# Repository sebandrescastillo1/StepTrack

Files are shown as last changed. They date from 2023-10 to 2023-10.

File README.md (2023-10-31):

# StepTrack - Contador de pasos en escalera
Repositorio contador de pasos 
## Contenido
- Librerias_eagle: Contiene librería de componentes de EAGLE utilizados para el contador de pasos.
- Documentos: Contiene los informes entregables de ELO301
- Datasheets: Contiene los datasheets de los componentes y otros documentos de interés.
- Entregable_PCB: Archivos entregables para PCB - COM & XLSX
- StepTruck_Esquematico.csv: BOM de EAGLE
- StepTruck_Esquematico.pdf: Esquemático EAGLE en formato pdf
- StepTruck_Esquematico.sch: ESquemático EAGLE en formato sch
- StepTruck_Esquematico.brd: Diseño PCB EAGLE en formato brd

## Autores
Grupo 2 - ELO301 S2 2023
- Paula Cartagena
- Sebastian Castillo
- Sebastian Madariaga
- Juan Piñeiro

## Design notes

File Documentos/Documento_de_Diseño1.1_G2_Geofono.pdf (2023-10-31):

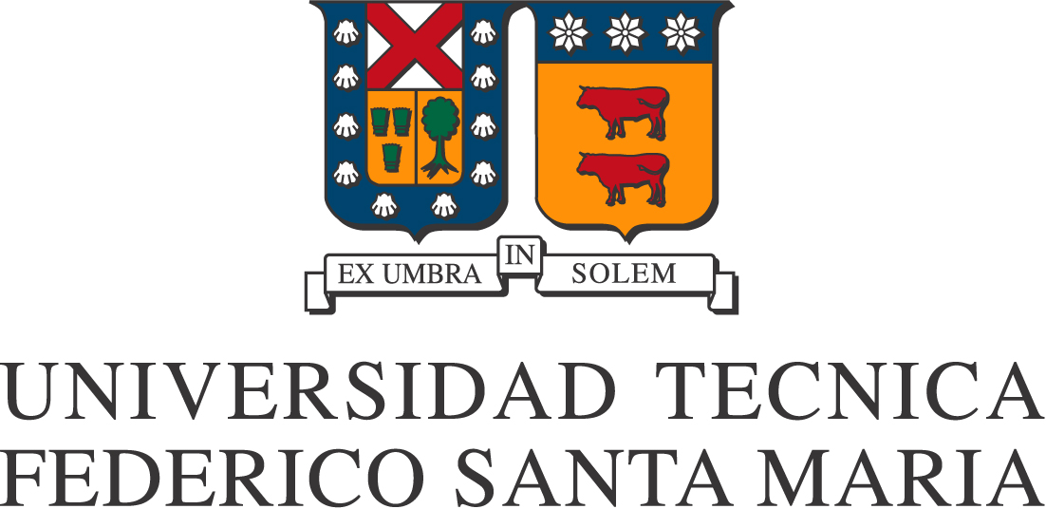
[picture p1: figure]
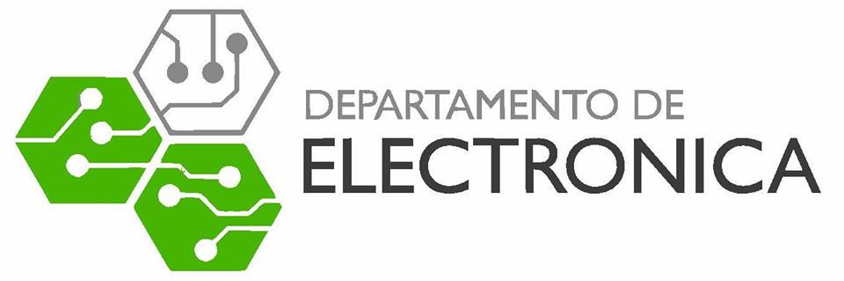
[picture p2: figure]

# Documento de diseño

# “Contador de pasos en escaleras”

Fecha | Revisión | Autor | Comentario
07/10/2023 | 1.0 | Paula Cartagena Sebastián Castillo Sebastián Madariaga Juan Piñeiro | Creación y desarrollo de documento
30/10/2023 | 1.1 | Paula Cartagena Sebastián Castillo Sebastián Madariaga Juan Piñeiro | Cambios de componentes a utilizar Cambio diagrama de bloques Cambio presupuesto y comentarios

Índice

1. Introducción. | 2
2. Funcionalidades Identificadas. | 3
2.1. Principales funcionalidades que debe cumplir el sistema | | 3
3. Elementos Identificados. | 3
3.1. | | | 3
4. Diseño de hardware propuesto. | 4
4.1. Diagrama de bloques | | 4
4.2. | | | 4
5. Diseño de firmware propuesto. | 5
5.1. Detalle de drivers | | 5
5.2. Diagrama de flujo | | 6
5.3. Detalle por módulo | | 6
6. Pruebas | 7
6.1. Prueba sobre elementos | | 7
| 6.1.1. Prueba 1: Prueba de geófono | | 7
| 6.1.2. Prueba 1: Prueba de geófono | | 8
6.2. Prueba sobre funcionalidades | | 8
| 6.2.1. Prueba 1 : Mensaje de Inicio | | 8
| 6.2.2. Prueba 2 : Prueba ADC | | 8
7. Cronograma | 9
8. Costos | 9

Índice de figuras

1. | Diagrama de Bloques | | 4
2. | Diagrama de flujo funcionamiento | | 6
Registro de especificaciones - Contador de pasos en escalera | 1

1 Introducción.

El sistema tiene la capacidad de contar la cantidad de pasos que se producen en una escalera mediante la detección de vibraciones capturadas por un geófono. Este dispositivo pasivo genera corriente eléctrica cuando capta vibraciones en su entorno, que en este caso es una escalera. Estas señales se digitalizan mediante un Convertidor Analógico a Digital (ADC) y luego se les aplica la Transformada Rápida de Fourier (FFT) para su filtrado y comparación con el estándar definido como "paso humano". Esto se logra mediante el análisis de los armónicos de frecuencia presentes en la señal. Si la señal cumple con los requisitos establecidos por el dispositivo, se lleva un registro de la cantidad de pasos ocurridos, junto con una marca de tiempo que indica el período de uso del equipo, es decir, desde el momento en que se conecta. Esta información, que incluye el número de pasos y la marca de tiempo, se envía en tiempo real en formato .csv al computador al que esté conectado a través de USB. Para reiniciar el conteo de pasos y la marca de tiempo, el dispositivo cuenta con un botón de reset.

Consideraciones:
El dispositivo se alimenta exclusivamente a través de un puerto USB de un computador, ya sea de USB-A o USB-C. Cuenta con un LED indicador de conexión que señala si está recibiendo energía, pero no garantiza una comunicación adecuada con el computador. Es responsabilidad del usuario verificar que la configuración de la comunicación esté correctamente ajustada de acuerdo al puerto COM de su portátil. Si se conecta a la red eléctrica mediante una caja de alimentación, el dispositivo pierde su funcionalidad principal.

Además, el dispositivo cuenta con un segundo LED que se enciende al recibir una señal de vibración proveniente del geófono. Este LED no indica la detección de un paso, sino simplemente la presencia de vibración, independientemente de su origen.

Es importante destacar que el dispositivo no almacena ningún tipo de dato. Sin embargo, cuenta con un pequeño búfer para almacenar el contador de pasos en caso de que se detecte una señal antes de que se pueda enviar la información al computador. La detección y el conteo de pasos son la prioridad, pero en caso de que este búfer se llene, se enviará toda la información a través de USB, sin importar si se pierde información, para evitar interrupciones. El dispositivo asume que la conexión con el computador siempre es satisfactoria y, por lo tanto, enviará datos incluso si no está abierta la API para recibir información.

Es importante tener en cuenta que el dispositivo no garantiza la eliminación de falsos positivos, sino que evalúa la señal conforme a los criterios establecidos. El contador de pasos se puede utilizar en cualquier tipo de escalera, incluyendo las de concreto.

Registro de especificaciones - Contador de pasos en escalera | 2

2 Funcionalidades Identificadas.

### 2.1 Principales funcionalidades que debe cumplir el sistema

Detectar señales (vibraciones) con un geófono.

Digitalizar señal análoga capturada para calcular FFT de ésta.

Filtrar espectro en frecuencia de señal capturada para evaluar si es un paso humano.

Llevar cuenta de la cantidad de pasos humanos identificados con su marca de tiempo.

Trasmitir información en formato .csv vía USB.

3 Elementos Identificados.

3.1

Microcontrolador STM32F103C8

(1) Geófono
(1) Botón de reset PTS526
(1) ADS1246IPWR
(1) Regulador de Voltaje: Torex Semiconductor XC6206P332MR-G.
(2) Leds;

1- LED BLANCO: indicador de encendido del dispositivo APA2107QWF
2- LED ROJO: indicador de detección de vibración (Geófono) C %SMF-RJE-CT0BB2.
(1) Conector USB-C: USB4105-GF-A
Registro de especificaciones - Contador de pasos en escalera | 3

4 Diseño de hardware propuesto.

### 4.1 Diagrama de bloques

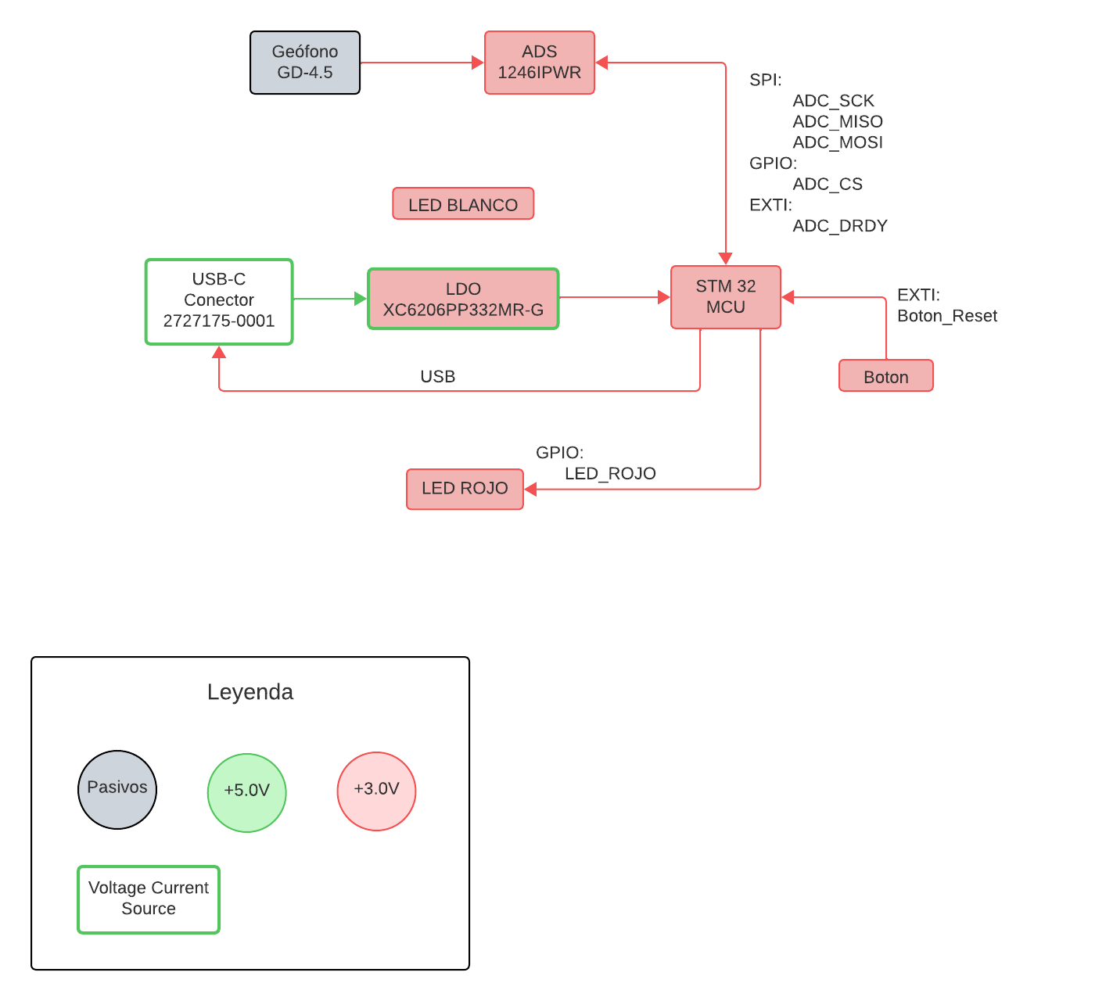
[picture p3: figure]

Figura 1: Diagrama de Bloques

4.2

Geófono: Componente pasivo, el cual genera una corriente cuando se produce una vibración en el medio físico con el cual tiene un contacto directo.

Botón de reset: Componente de interacción con el usuario, el cual setea en 0 la cantidad de pasos y reinicia el timer del MCU para llevar marca de tiempo.

LED BLANCO: Señal de luz que indica la correcta alimentación del dispositivo.

LED ROJO: Señal de luz que indica la captura de la señal análoga (vibraciones) por el geofono.

Registro de especificaciones - Contador de pasos en escalera | 4

Puerto USB-C: Puerto de conexión del dispositivo, a través de este se alimenta eléctricamente y además genera comunicación USB con Computador.

ADC Debe digitalizar la señal capturada por geófono, el ADS1246IPWR, cumple con los requisitos necesarios para tomar las muestras rápidamente y digitalizar con suficiente resolución para analizar espectralmente.

Regulador de Voltaje Componente electrónico para mantener estable el voltaje en 3.3V.

STM32 MCU Microcontrolador serie STM32F103C8 embebido a PCB que debe cumplir con las siguientes funciones:

- Generar conexión con PC para trasmitir los datos tomados.
- Calcular FFT de señal capturada.
- Filtrar señal espectral para comparar con criterios definidos.
- Resetear programa con Boton.

5 Diseño de firmware propuesto.

### 5.1 Detalle de drivers

arm_math.h Driver para poder calcular la FFT de la señal capturada. Disponible en CMSIS para STM32.

usb_device.h Driver para poder generar comunicación con PC.

ti-ads124x.h Driver para comunicar MCU con ADC mediante SPI.

Registro de especificaciones - Contador de pasos en escalera | 5

### 5.2 Diagrama de flujo

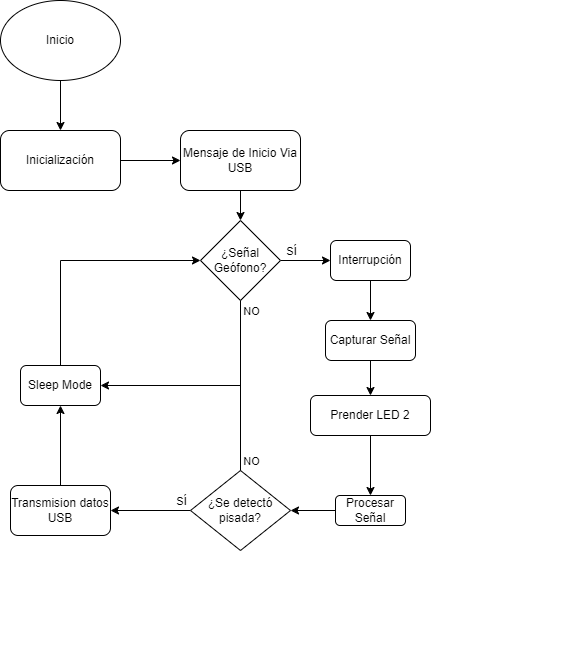
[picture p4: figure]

Figura 2: Diagrama de flujo funcionamiento

### 5.3 Detalle por módulo

Inicialización: Al inicializar el dispositivo, indicado por su LED1 de encendido, ocurre la inicialización del Firmware del dispositivo, es decir todos lo componentes y periféricos correspondientes.

Mensaje de Inicio Se envía un mensaje "Bienvenidos a Steptrack"mediante transmisión ,USB, indicando que el dispositivo ha inicializado correctamente el Firmware y se encuentra operativo para su funcionamiento.

Registro de especificaciones - Contador de pasos en escalera | 6

¿Señal del Géofono?: Este modulo es la abstracción de que el geófono está en posición para detectar vibraciones. Si no hay señal en el géofono este permanece en sleep mode, esperando que se detecte señal.

Interrupción Si el géofono capta una señal se produce una interrupción en el sistema.

Capturar Señal: Al producirse la interrupción el ADC digitaliza la señal para luego mediante SPI, ser leida por el MCU.

Prender LED 2: Se enciende LED2 que indica que el géofono capturó una señal.

Procesar Señal: Se aplica la transformada de Fourier Rápida, FFT para poder tener el espectro en frecuencia de la señal captada. Mediante técnicas de DSP, se filtra la señal para detectar los componentes en frecuencia de la señal, para determinar si cumple con los criterios establecidos.

¿Se detectó pisada?: Si la señal cumple con las características, se aumenta el contador de pasos y se guarda la marca de tiempo del sistema esto en formato .csv. Esta marca es el tiempo en ms en que se captó la pisada, desde que se inició el sistema. Si no se detecta pisada se va a Sleep mode.

Transmisión datos USB: Al detectar la pisada, se envía la información al PC conectado, esto mediante USB.

Sleep Mode: El sistema se queda en modo bajo consumo en caso de no detectar vibraciones.

Como alternativa a 2, se plantea, generar la captura de señal mediante polling, la cual puede generar varios problemas en tema de eficiencia del dispositivo, como el no captar señales debido a latencia del código.

Además se menciona que el boton de reset genera una interrupción de mayor prioridad que la del géofono, el cual setea el contador de pasos en 0, y se reinicia el tiempo del sistema. Al tratarse de una interrupción que no participa directamente en el flujo del funcionamiento se describe brevemente.

### 6 Pruebas

### 6.1 Prueba sobre elementos

### 6.1.1. Prueba 1: Prueba de geófono

Con el objetivo de probar el correcto funcionamiento del geófono se conectara un multitester para medir su corriente . El geófono al ser perturbado por una vibración genera una corriente , ya sea por un movimiento en su bobina sometida a su campo magnético (geófono de bobina movil) o una deformación en su material piezoelectrico (transducción piezoelectrica).

Registro de especificaciones - Contador de pasos en escalera | 7

### 6.1.2. Prueba 1: Prueba de geófono

Dentro de la PCB se incluirá un LED, que tendrá como función de indicador cuando el MCU detecte una señal captada por el geófono.

### 6.2 Prueba sobre funcionalidades

### 6.2.1. Prueba 1 : Mensaje de Inicio

Al iniciar el dispositivo , el microcontrolador mandará un mensaje hacia el ordenador enlazado con este vía USB.Dicho mensaje dirá “Bienvenidos a Steptrack”, indicando que el dispositivo ha inicializado correctamente el Firmware y se encuentra operativo para su funcionamiento.

### 6.2.2. Prueba 2 : Prueba ADC

Para probar todo el rango de lectura del ADC y el correcto funcionamiento de este, se utilizará un potenciómetro para medir todo el rango de valores del voltaje de salida del microcontrolador de 0 a 3.3V. Se enviará una señal USB desde el PC a la MCU para que este mande en tiempo real (vía USB a PC) la lectura del ADC. EL potenciómetro debe ser girado dentro todo su rango permitido para cambiar su resistencia, generando diferentes valores analógicos de voltaje y con ello el ADC generara diferentes valores digitales dentro del rango de resolución del ADC.

Registro de especificaciones - Contador de pasos en escalera | 8

### 7 Cronograma

| Semana 1 | Semana 2 | Semana 3 | Semana 4
DIseño industrial | X
Diseño esquemático | - | X | X | X
Diseño PCB | - | - | X | X
Compra de componentes | - | - | X | X
Compra y envío de PCB | - | - | X | X
Integración | - | - | - | -
Desarrollo de firmware | - | - | - | -
Pruebas | - | - | - | -

Tabla 1: Cronograma - 1

| Semana 5 | Semana 6 | Semana 7 | Semana 8
Diseño industrial
Diseño esquemático
Diseño PCB
Compra de componentes
Compra y envío de PCB
Integración | - | - | X | X
Desarrollo de firmware | X | X
Pruebas | - | - | X | X

Tabla 2: Cronograma - 2

### 8 Costos

Componentes | Descripción | Por 1 unidad | Precio unitario por 100 unidades
MCU | STM32F103C8T6 (https://www.digikey.com/es/products/detail/stmicroelectronics/STM32F103C8T6/1646338) | $6.42 | $4.79790
Botón de reset | Botón de reset (https://www.mouser.cl/ProductDetail/E-Switch/TL6190BUTTON?qs=QtyuwXswaQiUwZx8pGLR%2FA%3D%3D) | $0.24 | $0.22
ADC | ADS1246IPWR (https://www.digikey.com/es/products/detail/texas-instruments/ADS1246IPWR/2231572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) | $7.62000 | $5.69900
Led rojo | LED rojo (https://www.mouser.cl/ProductDetail/Cree-LED/C5SMF-RJE-CT0W0BB2?qs=1sbE9T7hb3bz%2FXMFB8lsHw%3D%3D) | $0.19 | $0.17
Led blanco | LED blanco (https://www.mouser.cl/ProductDetail/Cree-LED/C5SMF-GJE-CV0Y0792?qs=1sbE9T7hb3bE3wcoBIeGTA%3D%3D) | $0.27 | $0.23
Conector USB-C | USB-C SMT (https://www.digikey.com/es/products/detail/molex/2171750001/13913745?s=N4IgTCBcDa4IwHZEFYC0AGTcQF0C%2BQA) | $0.81000 | $0.55910
Regulador de voltaje | XC6206P332MR-G (https://www.mouser.cl/ProductDetail/Torex-Semiconductor/XC6206P332MR-G?qs=AsjdqWjXhJ%2FXxNpRY3zZ8g%3D%3D) | $0.8 | $0.5
Costo de envío | Tarifa única | $30 | $30
Total | | $50.25 | -

Tabla 3: Cotización

Los valores anteriormente provistos en la tabla son en Dolares(USD), se puede considerar la siguiente conversión de pesos chilenos a dolar con fecha 07/01/2023 como: 1USD = 909,69CLP.

Registro de especificaciones - Contador de pasos en escalera | 9

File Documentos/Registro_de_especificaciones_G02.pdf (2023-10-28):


# Registro de especificaciones

# “Contador de pasos en escaleras”

Fecha | Revisión | Autor | Comentario
10/09/2023 | 1.0 | Sebastian Castillo Paula Cartagena Sebastián Madariaga Juan Piñeiro | Creación y desarrollo de documento

### Índice

1. Identificación del cliente. | 2
2. Nombre del Equipo. | 2
3. Marco de referencia. | 2
4. Funcionalidad requerida y/o identificada. | 3
5. Alimentación utilizada. | 3
6. Empaquetamiento del equipo | 3
7. Características del medio donde será utilizado | 4
8. Costos objetivos del proyecto | 4
9. Certificaciones a cumplir | 4
10.Requerimientos especiales | 4

### Índice de figuras

Registro de especificaciones - Contador de pasos en escalera | 1

1 Identificación del cliente.

### 1.1 Fecha del requerimiento

Día 08 de Septiembre del 2023

### 1.2 Nombre del mandante

Álvaro Pablo Rene Aguirre Mattig

### 1.3 Persona de contacto

Álvaro Pablo Rene Aguirre Mattig

### 1.4 Datos de contacto

Correo electrónico: alvaro.aguirre@gmail.com

2 Nombre del Equipo.

Steptrack

3 Marco de referencia.

El sistema tiene la capacidad de contar la cantidad de pasos que se producen en una escalera mediante la detección de vibraciones específicas, las cuales son generadas por los pasos de personas. La información sobre la cantidad de pasos se transmite en tiempo real a una computadora a través de un puerto USB y se presenta en formato CSV para su posterior análisis en programas como Excel. El propósito principal de este dispositivo es evaluar tanto la estructura como el uso de una escalera, no importando si está hecha de concreto o si es una escalera flotante.

Este dispositivo cuenta con la capacidad de distinguir entre diferentes tipos de vibraciones con el fin de evitar falsos positivos, tales como movimientos tectónicos, ruidos ambientales intensos, el paso de camiones cercanos y movimientos estructurales del edificio, entre otros. La detección se lleva a cabo mediante el uso de geófonos, que son equipos pasivos cuyas señales son procesadas por el dispositivo. En tiempo real, el dispositivo transmite la información a la computadora a través de una conexión USB, y es importante destacar que el dispositivo se alimenta exclusivamente desde la computadora.

Es relevante mencionar que el dispositivo no almacena ningún tipo de dato, lo que significa que si no está transmitiendo información en un momento dado, los datos se pierden. Además, el dispositivo no entra en contacto directo con el suelo, ya que solo los geófonos lo hacen, por lo que no requiere protección contra las vibraciones de la escalera. Cuando se utiliza en escaleras al aire libre, el dispositivo cuenta con una protección IP68. Además, para informar sobre su funcionamiento, utiliza LEDs para indicar la transmisión de información y la conexión a la energía.

Registro de especificaciones - Contador de pasos en escalera | 2

4 Funcionalidad requerida y/o identificada.

### 4.1 Principales funcionalidades que debe cumplir el sistema

Detectar vibraciones.

Diferenciar pasos humanos de ruido.

Confirmar y contar pasos humanos.

Trasmitir información vía USB (serial)

### 4.2 Principales elementos que debe tener el sistema

Microcontrolador STM

Geófonos

Botón de reseteo

Leds

5 Alimentación utilizada.

Se energiza mediante conexión vía a USB, es decir con una alimentación de 5 Volts a 0,5 Amperios.

### 6 Empaquetamiento del equipo

### 6.1 Límites de tamaño

Se solicita un tamaño similar a la tarjeta de desarrollo STM32L476 Nucleo-64, aproximadamente 10 x 8 x 2 [cm].

### 6.2 Grado de protección

Debido a que se requiere que el dispositivo se posicione en zonas al aire libre pero techadas, considerando la meteorología de la región de Valparaíso, el dispositivo tiene certificación IP68, protección contra el agua y el polvo.

### 6.3 Geometría del equipo

Paralelepipedo rectangular

### 6.4 Materiales a utilizar

Sin material a utilizar.

Registro de especificaciones - Contador de pasos en escalera | 3

### 6.5 Interfaz física con el usuario

Para interfaz física de usuario debe haber un botón de reset que restablezca la cuenta y un LED que indique el correcto funcionamiento.

### 7 Características del medio donde será utilizado

### 7.1 Temperatura ambiental

Temperatura de la zona, correspondiente a la ciudad de Valparaíso, temperatura máxima promedio de 22-25 grados Celsius y una mínima promedio de 8-11 grados Celsius.

### 7.2 Humedad ambiental

Humedad de la zona, correspondiente a la ciudad de Valparaíso. Considerar que el producto va estar al aire libre y en interiores con su humedad correspondiente.En exteriores un porcentaje promedio máximo de 80 y mínimo 60 porciento.

### 7.3 Vibraciones

Los geofonos son lo que van adheridos a la estructura de la escalera, por lo que el dispositivo en sí no debe tener resistencia a las vibraciones.

### 7.4 Golpes

Resistencia estándar a caídas de menor altura.

### 8 Costos objetivos del proyecto

El costo de cada dispositivo tiene que ser de 15 dolares por unidad para una compra de 100 unidades.

### 9 Certificaciones a cumplir

No se requieren certificados.

### 10 Requerimientos especiales

No se presenta.

Registro de especificaciones - Contador de pasos en escalera | 4

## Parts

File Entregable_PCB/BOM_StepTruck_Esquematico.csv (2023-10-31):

Qty | Value | Device | Package | Parts | Description | POPULARITY | SPICEPREFIX
3 | 0 | R-US_R0805 | R0805 | R1, R2, R5 | RESISTOR, American symbol | 85 | R
8 | 100nF | C-USC0805K | C0805K | C3, C4, C5, C6, C7, C8, C9, C10 | CAPACITOR, American symbol | 19 | C
5 | 1k | R-US_R0805 | R0805 | R3, R4, R13, R14, R15 | RESISTOR, American symbol | 85 | R
2 | 1uF | C-USC0805K | C0805K | C1, C2 | CAPACITOR, American symbol | 19 | C
7 | 47 | R-US_R0805 | R0805 | R6, R7, R8, R9, R10, R11, R12 | RESISTOR, American symbol | 85 | R
1 | ADS1246IPWR | ADS1246IPWR | ADS1246IPWR | U1
1 | APA2107QWF/D | APA2107QWF/D | APA2107QWF/D | U5
1 | C5SMF-RJE-CT0W0BB2 | C5SMF-RJE-CT0W0BB2 | C5SMF-RJE-CT0W0BB2 | U4
1 | MKDSN1,5/2-5,08 | MKDSN1,5/2-5,08 | MKDSN1,5/2-5,08 | X1 | MKDSN 1,5/ 2-5,08 Printklemme | 14
1 | PTS526 | PTS526 | PTS526 | U8
1 | STM32F103C8T6 | STM32F103C8T6 | 48-LQFP | U2
1 | TS104TAA | TS104TAA | TS-104-T-AA | U6
1 | USB4105-GF-A | USB4105-GF-A | USB4105-GF-A | U3
1 | XC6206P33MR-G | XC6206P33MR-G | SOT-23 | U7

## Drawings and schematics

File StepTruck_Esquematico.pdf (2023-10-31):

# STEPTRACK

USB-C CONNECTOR | ADS1246

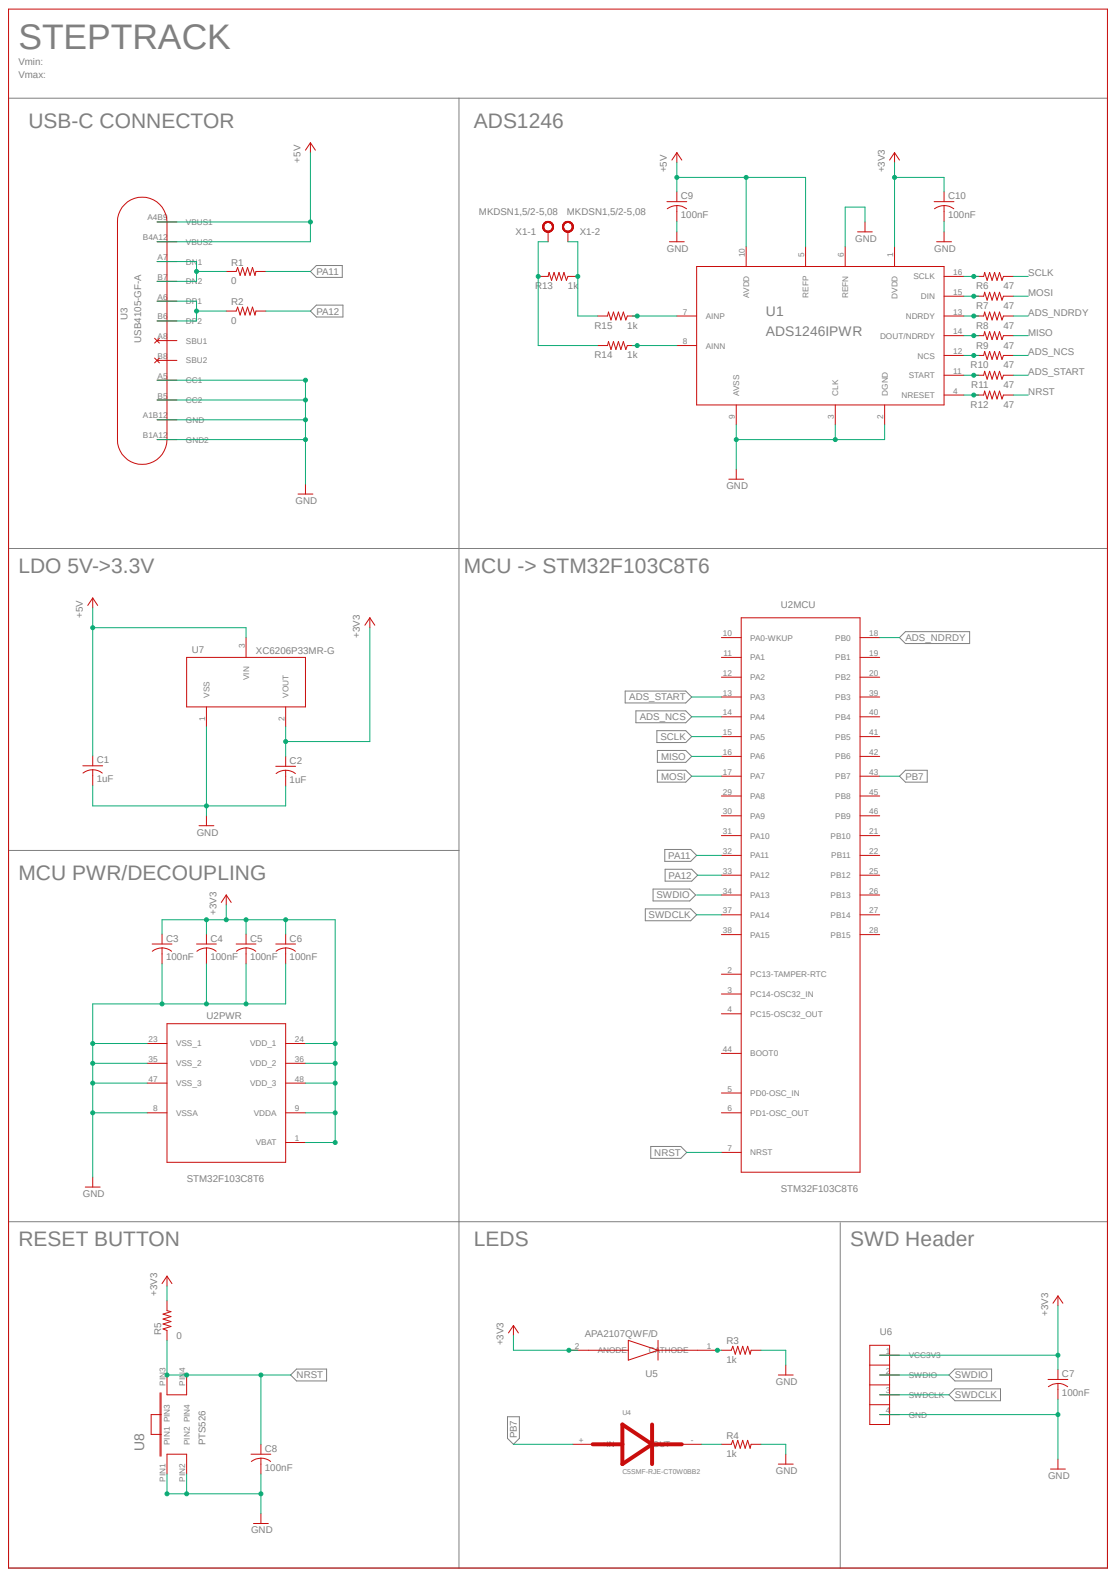
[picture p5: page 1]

1 SCLK 16 DIN 15 NDRDY 13 DOUT/NDRDY 14 NCS 12 START 11 NRESET 4 AINP 7 AINN 8 AVSS

U2MCU

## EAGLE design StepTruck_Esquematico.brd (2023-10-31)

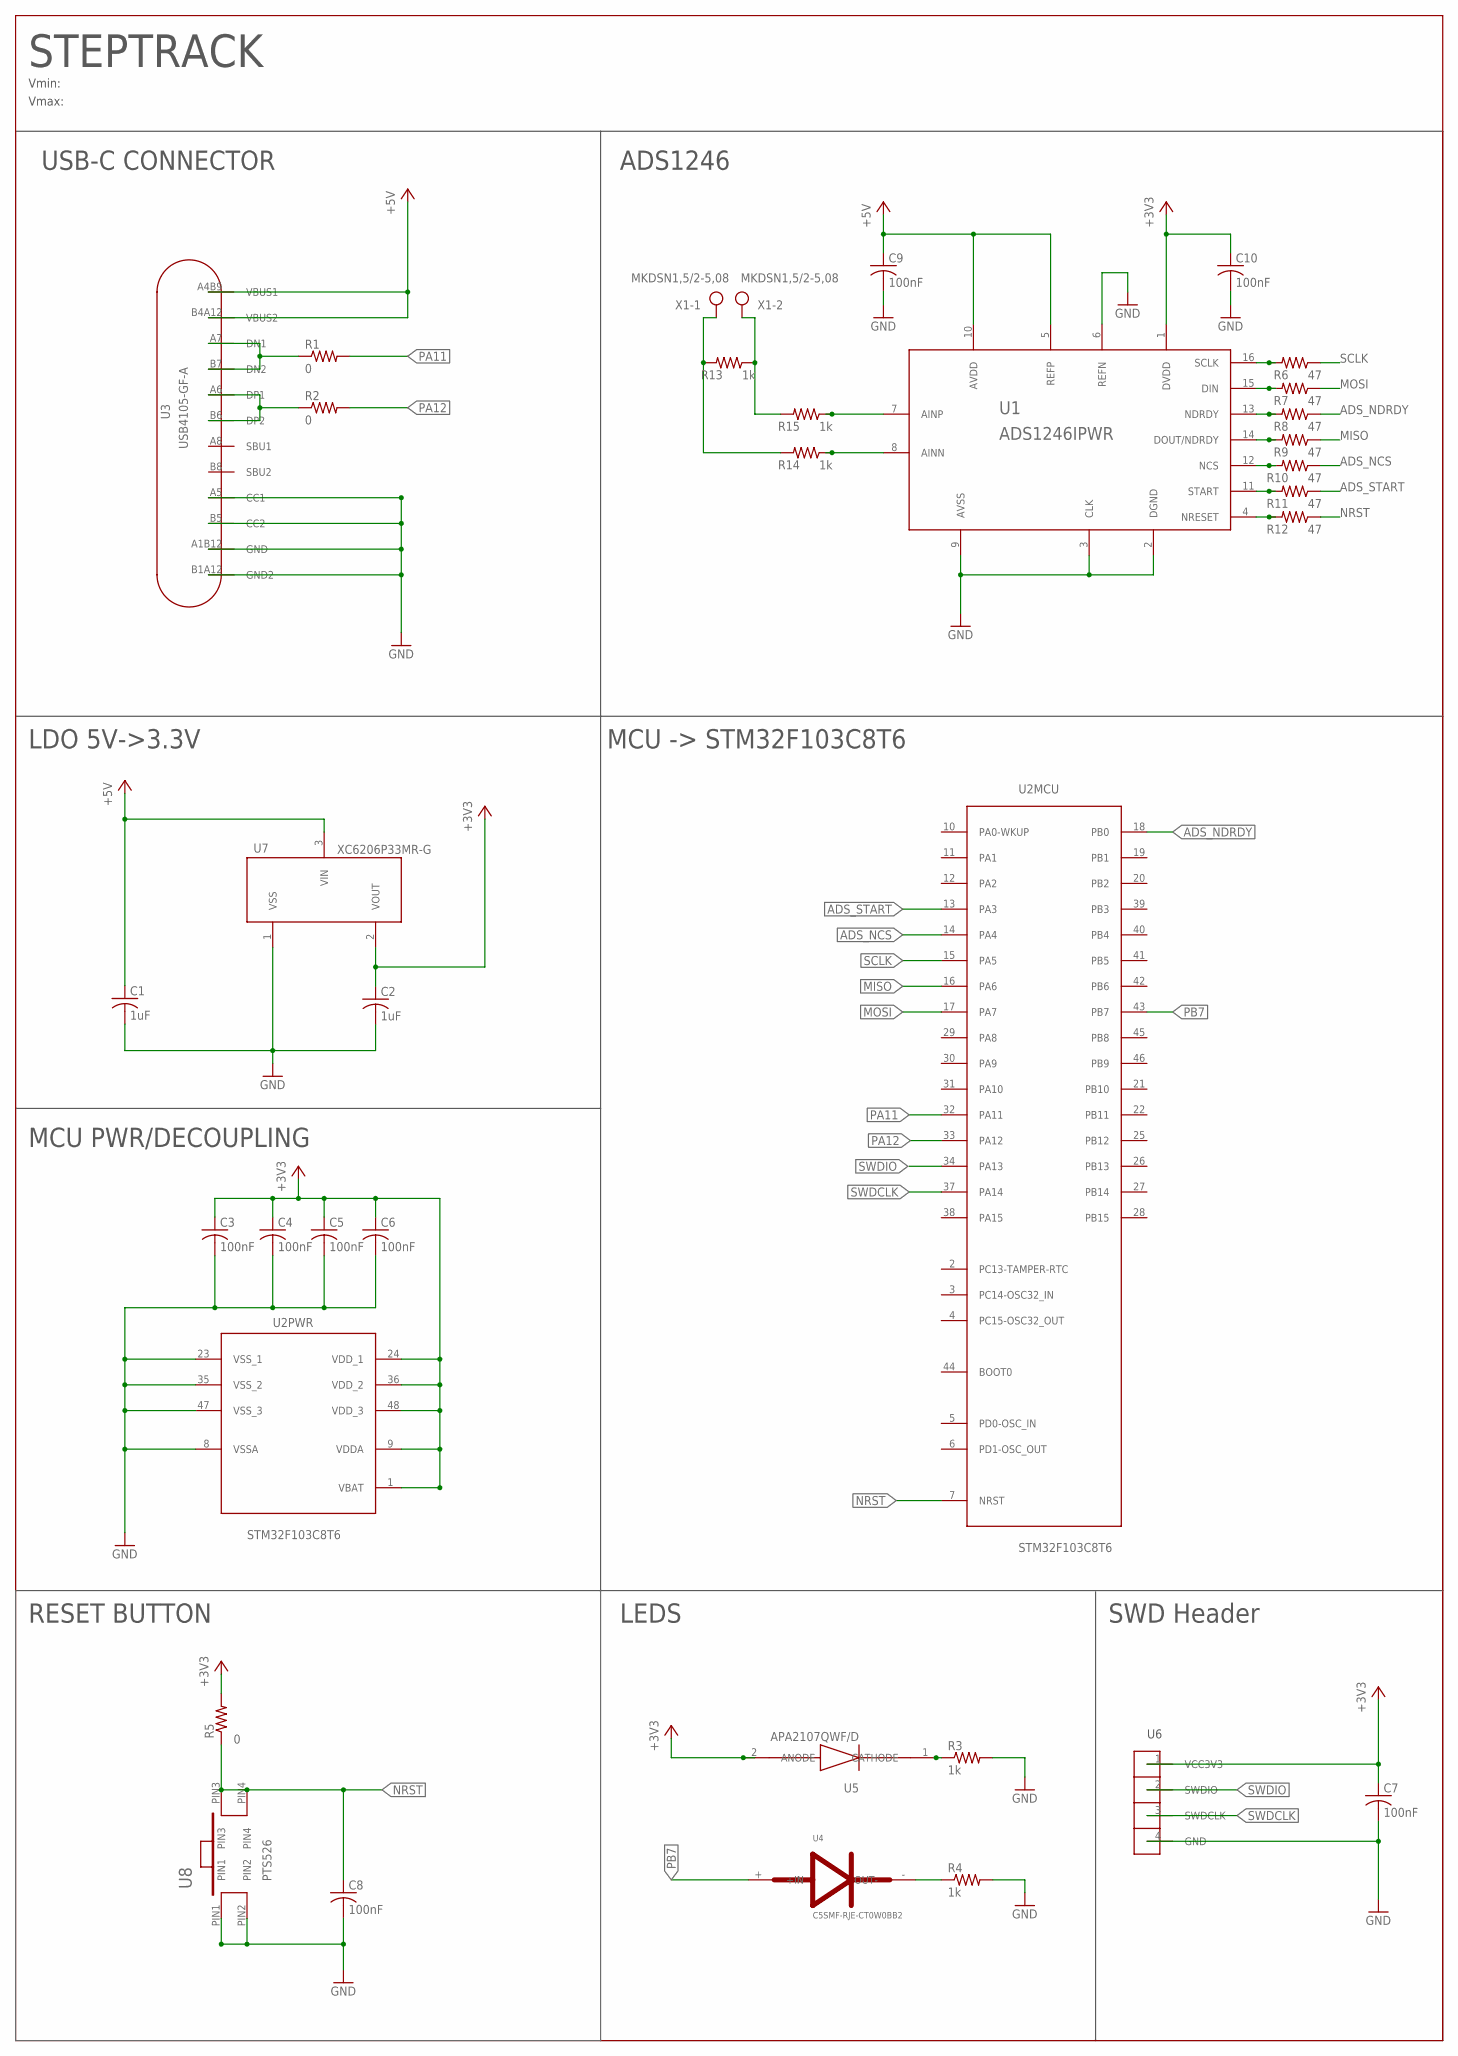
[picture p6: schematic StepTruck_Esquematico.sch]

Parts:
C1, C2: 1uF; C0805K
C3, C4, C5, C6, C7, C8, C9, C10: 100nF; C0805K
R1, R2, R5: 0; R0805
R3, R4, R13, R14, R15: 1k; R0805
R6, R7, R8, R9, R10, R11, R12: 47; R0805
U1: ADS1246IPWR
U2: STM32F103C8T6; 48-LQFP
U3: USB4105-GF-A
U4: C5SMF-RJE-CT0W0BB2
U5: APA2107QWF/D
U6: TS104TAA; TS-104-T-AA
U7: XC6206P33MR-G; SOT-23
U8: PTS526
X1: MKDSN1,5/2-5,08

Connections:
+3V3: C2.1, C3.1, C4.1, C5.1, C6.1, C7.1, C10.1, R5.2, U1.1 (DVDD), U2.1 (VBAT), U2.9 (VDDA), U2.24 (VDD_1), U2.36 (VDD_2), U2.48 (VDD_3), U5.2 (ANODE), U6.1 (VCC3V3), U7.2 (VOUT)
+5V: C1.1, C9.1, U1.5 (REFP), U1.10 (AVDD), U3.A4B9 (VBUS1), U3.B4A12 (VBUS2), U7.3 (VIN)
ADS_NCS: R10.1, U2.14 (PA4)
ADS_NDRDY: R8.1, U2.18 (PB0)
ADS_START: R11.1, U2.13 (PA3)
GND: C1.2, C2.2, C3.2, C4.2, C5.2, C6.2, C7.2, C8.2, C9.2, C10.2, R3.2, R4.2, U1.2 (DGND), U1.3 (CLK), U1.6 (REFN), U1.9 (AVSS), U2.8 (VSSA), U2.23 (VSS_1), U2.35 (VSS_2), U2.47 (VSS_3), U3.A1B12 (GND), U3.A5 (CC1), U3.B1A12 (GND2), U3.B5 (CC2), U6.4 (GND), U7.1 (VSS), U8.PIN1, U8.PIN2
MISO: R9.1, U2.16 (PA6)
MOSI: R7.1, U2.17 (PA7)
unnamed: R1.1, U3.A7 (DN1), U3.B7 (DN2)
unnamed: R15.1, U1.7 (AINP)
unnamed: R2.1, U3.A6 (DP1), U3.B6 (DP2)
unnamed: R14.1, U1.8 (AINN)
unnamed: R3.1, U5.1 (CATHODE)
unnamed: R4.1, U4.- (OUT-)
unnamed: R12.2, U1.4 (NRESET)
unnamed: R11.2, U1.11 (START)
unnamed: R10.2, U1.12 (NCS)
unnamed: R9.2, U1.14 (DOUT/NDRDY)
unnamed: R8.2, U1.13 (NDRDY)
unnamed: R7.2, U1.15 (DIN)
unnamed: R6.2, U1.16 (SCLK)
unnamed: R13.2, R14.2, X1.1
unnamed: R13.1, R15.2, X1.2
NRST: C8.1, R5.1, R12.1, U2.7 (NRST), U8.PIN3, U8.PIN4
PA11: R1.2, U2.32 (PA11)
PA12: R2.2, U2.33 (PA12)
PB7: U2.43 (PB7), U4.+ (+IN)
SCLK: R6.1, U2.15 (PA5)
SWDCLK: U2.37 (PA14), U6.3 (SWDCLK)
SWDIO: U2.34 (PA13), U6.2 (SWDIO)

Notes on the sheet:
STEPTRACK
USB-C CONNECTOR
ADS1246
MCU -> STM32F103C8T6
LDO 5V->3.3V
MCU PWR/DECOUPLING
RESET BUTTON
SWD Header
LEDS
Vmin:
Vmax:

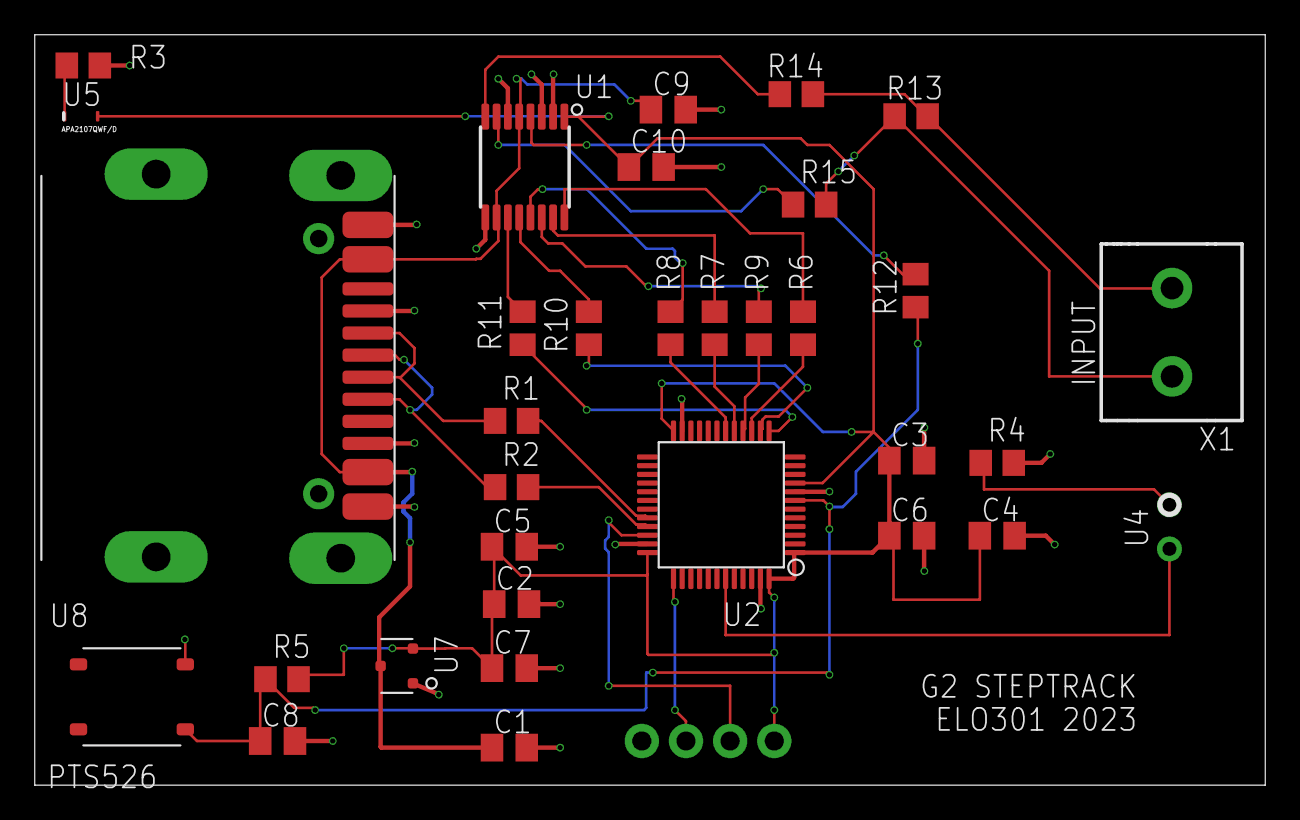
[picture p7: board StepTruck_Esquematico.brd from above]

Board: 2 copper layers, 70.8 x 43.2 mm, 34 parts (0 on the bottom side), 30 nets.

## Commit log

2023-10-18 Se sube contenido de eagle para STM32F103C8T6
2023-10-18 Se sube contenido de STM32F103C8T6
2023-10-18 Orden STM32
2023-10-18 Se agrega STM32 y LDO
2023-10-19 Nuevas versiones V2
    [BOM_STEPTRACK_V1.csv]
2023-10-28 Se agregan documentos anteriores + cambio de nombres
    [Bom.csv, Esquematico.sch]
2023-10-29 Actualizacion STM32
    Se arregla esquematico
2023-10-29 Add files via upload
    se coloca el part number al ADS
2023-10-30 Esquematico StepTrack
    Se sube esquemático modificado, con las mejoras propuestas y con terminaciones pulidas.
    [StepTruck_Esquematico.sch]
2023-10-30 Librerías de componentes actualizadas
    Se resuben los componentes modificados.
2023-10-30 Se actualizan archivos para esquematico
    [Bom.csv, Esquematico.sch, StepTruck_Esquematico.csv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]
2023-10-31 Actualizacion Esquematico
    [StepTruck_Esquematico.csv, StepTruck_Esquematico.sch]
2023-10-31 Entregable PCB
    [BOM_StepTruck_Esquematico.csv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]
2023-10-31 Documento de Diseño Actualizado
